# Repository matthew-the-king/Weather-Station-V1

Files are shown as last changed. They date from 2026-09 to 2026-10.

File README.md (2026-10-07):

# Weather-Station-V1
The Weather Station V1 is a Solar- and Battery-powered Weather Station that measures humidity, pressure, temperature, and air quality, and sends all data over Wi-Fi for a client to receive or records it to an SD card.
Weather_Station_2026-Oct-04_05-36-57PM-000_CustomizedView7621450915

## |FEATURES IN DEPTH|<br>
The Weather Station V1 uses multiple sensors to collect data; here is the list:<br>
1.STS40-AD1B-R3(Temperature Sensor)<br>
2.BMP581(Pressure Sensor)<br>
3.ENS160-BGLT(Air qaulity Sensor)<br>
4.SAM-M10Q-00B(GPS IC)<br>
To view the data the Weather Station V1 collects, the PCB has an SD card slot that records data over long periods and an ESP32-C3 that can send data over WiFi.<br>

<br>
The Weather Station V1 can be powered with a solar panel. To hook up the solar panel, connect the power wires with the correct polarity to the blue screw-in terminal. Here is the [link](https://www.amazon.com/ECO-WORTHY-Monocrystalline-Waterproof-Charging-Applications/dp/B01IFJ73X4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), it cost around $29(As of october 10, 2026), to the Solar panel I am using; any Solar panel that can supply over 2 amps and more than 20 volts will work.<br>
<br>
Weather_Station_2026-Oct-07_04-39-36AM-000_CustomizedView14020761017<br>
The Weather Station V1 features an LTC4162, which is a LiFePO4 battery step-down charger with a Power path. To set up the cell count properly, JP1 and JP4 must be bridged. 
The PCB includes a port for soldering a thermistor for battery protection.

The current configuration of the PCB requires 4 LiFePO4 batteries(https://www.digikey.com/en/products/detail/zeus-battery-products/PCIFR18650-1500/9828824)
The PCB has THT 18650 Battery holder footprint on the bottom side of the board, allowing for quick and easy connection of batteries to the PCB.<br>
<br>
The board has a USB-C port for each MCU to make programming as easy as possible, but in case the user does not want to use USB programming, there are also header pins on the other side of the
board that allow for ESP32 UART programming and STM32 serial wire debug and programming.<br>


<br>
## |PRODUCTION|<br>
To produce the PCB, use your preferred PCB manufacturer (PCBway, JLCPCB, etc.).  The Bill of Materials is listed here:<br>
* If Digi-Key does not have the part stocked, check other vendors like Mouser. <br>
*Prices as of October 10, 2026<br>

| Designator | Footprint | Qty | Value / Part | Part Link |Price|
|---|---|---:|---|---|---|
| BT5 | BAT_BK-18650-PC8 | 1 | BK-18650-PC8 | [Link](https://www.digikey.com/en/products/detail/mpd-memory-protection-devices/BK-18650-PC8/2330515)|$6.22|
| C1 | 0603 | 1 | 330nF | [Link](https://www.digikey.com/en/products/detail/tdk/CGA3E3X7R1H334K080AB/4931465)|$0.26|
| C10, C27, C3, C38, C39, C4, C40, C41, C45, C46, C5, C50, C51, C52, C53, C54, C6, C62, C63, C64, C9 | 0402 | 21 | 0.1uF |[Link](https://www.digikey.com/en/products/detail/samsung-electro-mechanics/CL05A104KA5NNNC/3886701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) | $0.38|
| C11, C37, C44, C57, C65 | 0402 | 5 | 10uF |[Link](https://www.digikey.com/en/products/detail/murata-electronics/GRM155R60J106ME15D/5877401) |$0.85|
| C12, C13, C16, C42, C43, C61, C66 | 0402 | 7 | 1uF |[Link](https://www.digikey.com/en/products/detail/samsung-electro-mechanics/CL05A105KO5NNNC/3886725) |$0.70|
| C14 | 0402 | 1 | 22nF |[Link](https://www.digikey.com/en/products/detail/murata-electronics/GRM155R71H223KA12D/965898) |$0.11|
| C15, C18, C2, C24, C26, C7 | 1210 | 6 | 10uF |[Link](https://www.digikey.com/en/products/detail/murata-electronics/GCJ32EC71H106KA01K/9867929) |$7.08|
| C17, C22, C23, C29, C60, C67, C68, C69 | 0603 | 8 | 0.1uF |[Link](https://www.digikey.com/en/products/detail/kemet/C0603C104K5RACTU/1465594)|$1.12|
| C25, C28 | CAP_EEH-ZA1V151P_PAN | 2 | 150uF |[Link](https://www.digikey.com/en/products/detail/panasonic-industry/EEH-ZA1V151P/3088122) |$3.52|
| C34, C35, C36 | 0805 | 3 | 220nF |[Link](https://www.digikey.com/en/products/detail/kemet/C0805C224K5RACTU/754753) |$0.93|
| C47, C48 | 0201 | 2 | C |Will Post link when Done with testing||
| C49 | 0603 | 1 | 4.7uF |[Link](https://www.digikey.com/en/products/detail/murata-electronics/GRM188R61E475KE11D/3900465) |$0.24|
| C55, C8 | 0603 | 2 | 22uF |[Link](https://www.digikey.com/en/products/detail/holy-stone-enterprise-co-ltd/C0603B226M010T/16895513) |$0.68|
| C56 | WCAP-PSHP_8X8.7_DXL_ | 1 | 470uF |[Link](https://www.digikey.com/en/products/detail/w%C3%BCrth-elektronik/875115252003/5147615) |$1.32|
| C58 | 0402 | 1 | 470pF |[Link](https://www.digikey.com/en/products/detail/murata-electronics/GRM1555C1H471JA01D/587210) |$0.10|
| C59 | 0402 | 1 | 100pF |[Link](https://www.digikey.com/en/products/detail/murata-electronics/GRM1555C1H101JA01D/3693829) |$0.11|
| D1, D5, D6 | D_SOD-123F | 3 | 40V |[Link](https://www.digikey.com/en/products/detail/smc-diode-solutions/DSS14U/8341859) |$0.63|
| D2 | D_SMA | 1 | D |[Link](https://www.digikey.com/en/products/detail/mcc-micro-commercial-components/SK310A-LTP/2642015) |$0.52|
| D3 | D_SOD-123 | 1 | Zener 16V |[Link](https://www.digikey.com/en/products/detail/diodes-incorporated/DDZ9703-7/5218356) |$0.36|
| D4 | D_SMA | 1 | 100V |[Link](https://www.digikey.com/en/products/detail/mcc-micro-commercial-components/SK310A-LTP/2642015) |$0.52|
| ESP32_USB1, STM32_USB1 | SAMESKY_UJ20-C-H-G-SMT-P16-TR | 2 | UJ20-C-H-G-SMT-1-P16-TR |[Link](https://www.digikey.com/en/products/detail/same-sky-formerly-cui-devices/UJ20-C-H-G-SMT-P16-TR/24818595) |$1.30|
| FB1, FB2 | 0603 | 2 | 120R |[Link](https://www.digikey.com/en/products/detail/pulse-electronics/PE-0603PFB121ST/5050544) |$0.20|
| J1 | GCT_MEM2075-00-140-01-A | 1 | MEM2075-00-140-01-A |[Link](https://www.digikey.com/en/products/detail/gct/MEM2075-00-140-01-A/9859614) |$1.92|
| J2 | TE_CONREVSMA002 | 1 | CONREVSMA002 |[Link](https://www.digikey.com/en/products/detail/te-connectivity-linx/CONREVSMA002/340145) |$2.78|
| J3 | PinHeader_1x05_P2.54mm_Vertical | 1 | Conn_01x05_Pin |2.54mm Male Header Pins|
| J4 | PinHeader_1x04_P2.54mm_Vertical | 1 | Conn_01x04_Pin |2.54mm Male Header Pins|
| J5 | OST_OSTTC020162 | 1 | Solar Panel |[Link](https://www.digikey.com/en/products/detail/on-shore-technology-inc/OSTTC020162/614549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) | $0.62|
| JP8, JP9 | PinSocket_1x02_P2.54mm_Vertical | 2 | Jumper_2_Open |2.54mm Male Header Pins|
| L1 | IND_PA4342.402NLT | 1 | 4uH |[Link](https://www.digikey.com/en/products/detail/pulse-electronics/PA4342-402NLT/5641799) |$1.16|
| L2 | 0201 | 1 | L |Will Post link when Done with testing||
| L3 | 1008 | 1 | 1.5uH |[Link](https://www.digikey.com/en/products/detail/murata-electronics/DFE252012P-1R5M-P2/5247259) |$0.22|
| Q10, Q9 | NPNBEC_SOT-23_OSI | 2 | BSR14 |[Link](https://www.digikey.com/en/products/detail/onsemi/BSR14/965251) |$0.96|
| Q11, Q14 | WDFN8_511DR_OSI-L | 2 | FDMC8327L |[Link](https://www.digikey.com/en/products/detail/onsemi/FDMC8327L/4314821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) |$3.00|
| Q3, Q4, Q5, Q6 | TDSON-8-1 | 4 | CSD18534Q5A |[Link](https://www.digikey.com/en/products/detail/texas-instruments/CSD18534Q5A/3830016) |$6.84|
| R1 | 1206 | 1 | 16mΩ |[Link](https://www.digikey.com/en/products/detail/littelfuse-inc/L4CL1206LR016DNR/18795436) |$1.31|
| R10, R11 | 2512 | 2 | 10MΩ |[Link](https://www.digikey.com/en/products/detail/bourns-inc/CHV2512-JW-106ELF/5175992) |$1.02|
| R12, R13, R8, R9 | 0603 | 4 | 330Ω |[Link](https://www.digikey.com/en/products/detail/yageo/RC0603FR-07330RL/727162) |$0.40|
| R14 | 0603 | 1 | 63.4k |[Link](https://www.digikey.com/en/products/detail/yageo/RT0603BRD0763K4L/1072610) |$0.10|
| R15, R16 | 0402 | 2 | 10k |[Link](https://www.digikey.com/en/products/detail/yageo/RC0402JR-0710KL/726418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) |$0.11|
| R2, R3, R39, R40 | 0402 | 4 | 4.7kΩ |[Link](https://www.digikey.com/en/products/detail/yageo/RC0402JR-074K7L/726477) |$0.44|
| R20, R25 | 0603 | 2 | 300Ω |[Link](https://www.digikey.com/en/products/detail/yageo/RC0603FR-07300RL/724356) |$0.20|
| R21, R22 | 2512 | 2 | 80.6Ω |[Link](https://www.digikey.com/en/products/detail/koa-speer-electronics-inc/RK73H3ATTE80R6F/10423948) |$0.62|
| R23, R24, R26, R47, R48, R51, R52, R7 | 2010 | 8 | 100Ω |[Link](https://www.digikey.com/en/products/detail/yageo/RT2010FKE07100RL/5945596) |$1.28|
| R27, R28, R29, R30 | 0402 | 4 | 5.1kΩ |[Link](https://www.digikey.com/en/products/detail/yageo/RC0402FR-075K1L/726624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) |$0.40|
| R31, R32, R33, R34, R37, R38, R43, R45, R49 | 0402 | 9 | 10kΩ |[Link](https://www.digikey.com/en/products/detail/yageo/RC0402JR-0710KL/726418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) |$0.99|
| R35, R36 | 0402 | 2 | 22Ω |[Link](https://www.digikey.com/en/products/detail/yageo/RC0402FR-0722RL/726562) |$0.22|
| R41 | 0402 | 1 | 100k |[Link](https://www.digikey.com/en/products/detail/yageo/RC0402FR-07100KL/726526) |$0.10|
| R42 | 0402 | 1 | 31.6kΩ |[Link](https://www.digikey.com/en/products/detail/panasonic-industry/ERA-2AEB3162X/2026187) |$0.11|
| R44, R53 | 0402 | 2 | 100kΩ |[Link](https://www.digikey.com/en/products/detail/yageo/RC0402FR-07100KL/726526) |$0.10|
| R46 | MSRSF3920P1L00D2P0 | 1 | 1mΩ |[Link](https://www.digikey.com/en/products/detail/susumu/MSRSF3920P-1L00-D2P0/24396792) |$1.74|
| R50 | 0805 | 1 | 32mΩ |[Link](https://www.digikey.com/en/products/detail/vishay-dale/WSLP0805R0320FEA/9755276) |$1.29|
| S1 | SW_SKRPABE010 | 1 | SKRPABE010 |[Link](https://www.digikey.com/en/products/detail/alps-alpine/SKRPABE010/18768948) |$0.22|
| TH1 | PinHeader_1x02_P1.00mm_Vertical | 1 | 103AT2 |[Link](https://www.digikey.com/en/products/detail/semitec-usa-corp/103AT-2/16579059?s=N4IgTCBcDaIIwAYDMBBAKhAugXyA) |$0.68|
| U1 | UFQFPN-32_STM | 1 | STM32U385KGU6 |[Link](https://www.digikey.com/en/products/detail/stmicroelectronics/STM32U385KGU6/26092104) |$7.31|
| U10 | VQFN20_RGR_TEX | 1 | BQ76907RGRR |[Link](https://www.digikey.com/en/products/detail/texas-instruments/BQ76907RGRR/22077514) |$2.01|
| U11 | SOT-23-5 | 1 | MIC5504-1.8YM5 |[Link](https://www.digikey.com/en/products/detail/microchip-technology/MIC5504-1-8YM5-TR/5209404) |$0.16|
| U12, U13 | PSON50P145X100X60-6N | 2 | TPD4S012DRYR |[Link](https://www.digikey.com/en/products/detail/texas-instruments/TPD4S012DRYR/2037539) |$2.38|
| U14 | IC_MCP16362T-E_NMX | 1 | MCP16362T-E_NMX |[Link](https://www.digikey.com/en/products/detail/microchip-technology/MCP16362T-E-NMXVAO/14291783) |$2.33|
| U2 | QFN10_BMP581_BOS | 1 | BMP581 |[Link](https://www.digikey.com/en/products/detail/bosch-sensortec/BMP581/16036134) |$3.35|
| U3 | STS4X | 1 | STS4X |[Link](https://www.digikey.com/en/products/detail/sensirion-ag/STS40-AD1B-R3/16020549) |$0.72|
| U4 | XDCR_ENS210-LQFM | 1 | ENS210-LQFM |[Link](https://www.digikey.com/en/products/detail/sciosense/ENS210-LQFM/6490747) |$1.62|
| U5 | XDCR_ENS160-BGLT | 1 | ENS160-BGLT |[Link](https://www.digikey.com/en/products/detail/sciosense/ENS160-BGLT/16129831) |$5.72|
| U6 | QFN50P500X500X90-33N | 1 | LTC4162IUFD-FAD_PBF |[Link](https://www.digikey.com/en/products/detail/analog-devices-inc/LTC4162IUFD-FAD-PBF/9446112) |$9.96|
| U7 | XCVR_SAM-M10Q-00B | 1 | SAM-M10Q-00B |[Link](https://www.digikey.com/en/products/detail/u-blox/SAM-M10Q-00B/16672678) |$13.75|
| U8 | QFN50P500X500X90-33N | 1 | ESP32-C3FH4 |[Link](https://www.digikey.com/en/products/detail/espressif-systems/ESP32-C3FH4/14115592) |$2.50|
| Y3 | OSC_ECS-2520S33-400-FN-TR | 1 | 40MHZ |[Link](https://www.digikey.com/en/products/detail/ecs-inc/ECS-2520S33-400-FN-TR/6578428) |$2.25|

Make sure you also purchase an antenna for the RF port; any SMA-Male antenna works. Here is a [link](https://www.digikey.com/en/products/detail/inventek-systems/W24-ASMA-M/4959494) for one.<br>
The total cost of all the PCB components is 135.59 dollars as of right now, with shipping being around an extra $5; when I add the PI filter stuff, it will only go up a dollar max.<br>
I would greatly recommend using a PCB stencil to make soldering components easier, as some of the components are quite small. Remember, in order for the battery functionality to work, JP1 and JP4 must be bridged.<br>
<br>

## |Weather Station Case|<br>
I CAD'd a 3D-printable case for the Weather Station V1 PCB; it has two parts: a front plate and a container part.
There are M.2 threaded insert holes on the container part, so you must purchase threaded inserts and M.2 screws.<br>
<br>

## |Firmware|<br>
So far, I have only added main.cpp, which should be placed in an STM32CubeIDE project.  No code has been written into it yet because I do not have the board to program yet. 

## |Purpose Of Project |<br>
The purpose of the Weather Station V1 was to enhance my understanding of RF applications and battery- and solar-powered devices. Throughout making this project, I understood RF design better and overall PCB design.
I hope this knowledge will allow me to make better, more reliable, and cooler projects in the future.

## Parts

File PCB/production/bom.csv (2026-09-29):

Designator | Footprint | Quantity | Value | LCSC Part #
BT5 | BAT_BK-18650-PC8 | 1 | BK-18650-PC8
C1 | 0603 | 1 | 330nF
C10, C27, C3, C38, C39, C4, C40, C41, C45, C46, C5, C50, C51, C52, C53, C54, C6, C62, C63, C64, C9 | 0402 | 21 | 0.1uF
C11, C37, C44, C57, C65 | 0402 | 5 | 10uF
C12, C13, C16, C42, C43, C61, C66 | 0402 | 7 | 1uF
C14 | 0402 | 1 | 22nF
C15, C18, C2, C24, C26, C7 | 1210 | 6 | 10uF
C17, C22, C23, C29, C60, C67, C68, C69 | 0603 | 8 | 0.1uF
C25, C28 | CAP_EEH-ZA1V151P_PAN | 2 | 150uF
C34, C35, C36 | 0805 | 3 | 220nF
C47, C48 | 0201 | 2 | C
C49 | 0603 | 1 | 4.7uF
C55, C8 | 0603 | 2 | 22uF
C56 | WCAP-PSHP_8X8.7_DXL_ | 1 | 470uF
C58 | 0402 | 1 | 470pF
C59 | 0402 | 1 | 100pF
D1, D5, D6 | D_SOD-123F | 3 | 40V
D2 | D_SMA | 1 | D
D3 | D_SOD-123 | 1 | Zener 16V
D4 | D_SMA | 1 | 100V
ESP32_USB1, STM32_USB1 | SAMESKY_UJ20-C-H-G-SMT-P16-TR | 2 | UJ20-C-H-G-SMT-1-P16-TR
FB1, FB2 | 0603 | 2 | 120R
J1 | GCT_MEM2075-00-140-01-A | 1 | MEM2075-00-140-01-A
J2 | TE_CONREVSMA002 | 1 | CONREVSMA002
J3 | PinHeader_1x05_P2.54mm_Vertical | 1 | Conn_01x05_Pin
J4 | PinHeader_1x04_P2.54mm_Vertical | 1 | Conn_01x04_Pin
J5 | OST_OSTTC020162 | 1 | Solar Panel
JP1, JP2, JP3, JP4, JP5, JP6, JP7 | SolderJumper-2_P1.3mm_Open_TrianglePad1.0x1.5mm | 7 | Jumper_2_Open
JP8, JP9 | PinSocket_1x02_P2.54mm_Vertical | 2 | Jumper_2_Open
L1 | IND_PA4342.402NLT | 1 | 4uH
L2 | 0201 | 1 | L
L3 | 1008 | 1 | 1.5uH
Q10, Q9 | NPNBEC_SOT-23_OSI | 2 | BSR14
Q11, Q14 | WDFN8_511DR_OSI-L | 2 | FDMC8327L
Q3, Q4, Q5, Q6 | TDSON-8-1 | 4 | CSD18534Q5A
R1 | 1206 | 1 | 16mΩ
R10, R11 | 2512 | 2 | 10MΩ
R12, R13, R8, R9 | 0603 | 4 | 330Ω
R14 | 0603 | 1 | 63.4k
R15, R16 | 0402 | 2 | 10k
R2, R3, R39, R40 | 0402 | 4 | 4.7kΩ
R20, R25 | 0603 | 2 | 300Ω
R21, R22 | 2512 | 2 | 80.6Ω
R23, R24, R26, R47, R48, R51, R52, R7 | 2010 | 8 | 100Ω
R27, R28, R29, R30 | 0402 | 4 | 5.1kΩ
R31, R32, R33, R34, R37, R38, R43, R45, R49 | 0402 | 9 | 10kΩ
R35, R36 | 0402 | 2 | 22Ω
R41 | 0402 | 1 | 100k
R42 | 0402 | 1 | 31.6kΩ
R44, R53 | 0402 | 2 | 100kΩ
R46 | MSRSF3920P1L00D2P0 | 1 | 1mΩ
R50 | 0805 | 1 | 32mΩ
S1 | SW_SKRPABE010 | 1 | SKRPABE010
TH1 | PinHeader_1x02_P1.00mm_Vertical | 1 | 103AT2
U1 | UFQFPN-32_STM | 1 | STM32U385KGU6
U10 | VQFN20_RGR_TEX | 1 | BQ76907RGRR
U11 | SOT-23-5 | 1 | MIC5504-1.8YM5
U12, U13 | PSON50P145X100X60-6N | 2 | TPD4S012DRYR
U14 | IC_MCP16362T-E_NMX | 1 | MCP16362T-E_NMX
U2 | QFN10_BMP581_BOS | 1 | BMP581
U3 | STS4X | 1 | STS4X
U4 | XDCR_ENS210-LQFM | 1 | ENS210-LQFM
U5 | XDCR_ENS160-BGLT | 1 | ENS160-BGLT
U6 | QFN50P500X400X80-29N | 1 | LTC4162IUFD-FAD_PBF
U7 | XCVR_SAM-M10Q-00B | 1 | SAM-M10Q-00B
U8 | QFN50P500X500X90-33N | 1 | ESP32-C3FH4
Y3 | OSC_ECS-2520S33-400-FN-TR | 1 | 40MHZ

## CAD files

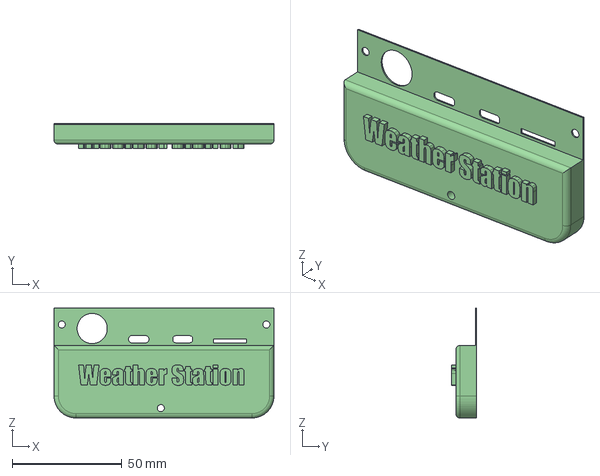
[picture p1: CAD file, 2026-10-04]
CAD/Front_Plate.step
100.0 x 11.5 x 50.0 mm

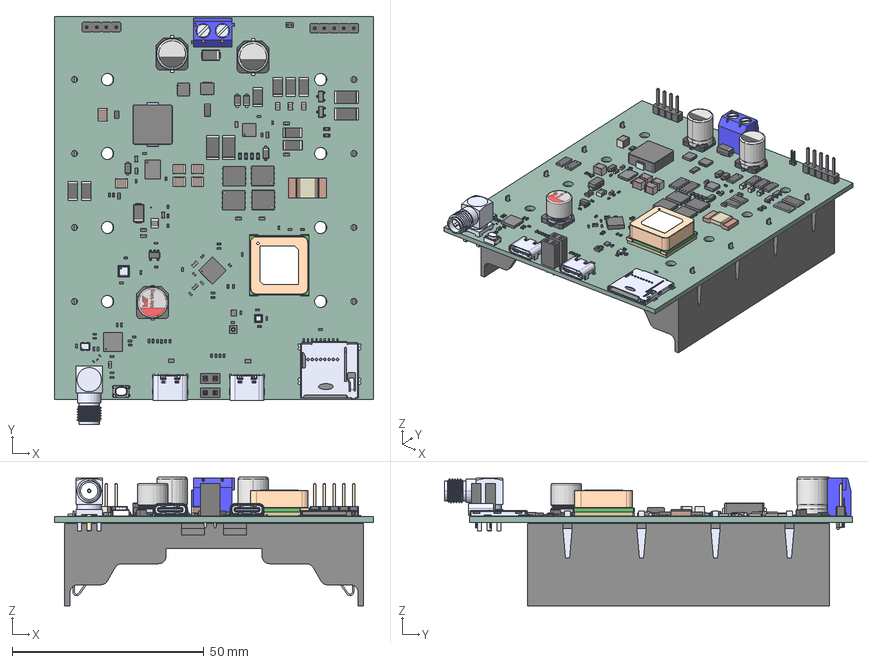
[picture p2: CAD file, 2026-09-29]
PCB/Weather_Station.step
83.4 x 106.5 x 33.6 mm
C_0603_1608Metric x 12
C_0402_1005Metric x 38
R_0402_1005Metric x 23
MSRSF3920P-1L00-D2P0
ECS-2520S33-200-FN-TR
C_0201_0603Metric x 2
R_0603_1608Metric x 7
R_0805_2012Metric
PinSocket_1x02_P2.54mm_Vertical x 2
EEHZF1E151P x 2
C_1210_3225Metric x 6
SKRPABE010
C_0805_2012Metric x 3
Same_Sky_UJ20-C-H-G-SMT-P16-TR x 2
SOT23 x 2
RGR20
R_2512_6332Metric x 4
R_2010_5025Metric x 8
MEM2075-00-140-01-A
L_1008_2520Metric
148907-01_Publikationsmodell STS4x
L_0603_1608Metric x 2
LTC2323HUFD-14#PBF
ENS210-LQFM
BMP581
SAM-M10Q-00B
TDSON_8_1 x 4
CONREVSMA002
D_SOD_123F x 3
ESP32-C3FH4
D_SOD-123
Base_Φ8Capacitor
capicitor_8x8.7x3.1
DRY6 x 2
L_0201_0603Metric
PinHeader_1x04_P254mm_Vertical
R_1206_3216Metric
PA4342.402NLT
SOT-23-5
D_SMA x 2
PinHeader_1x02_P100mm_Vertical
PinHeader_1x05_P254mm_Vertical
ENS160-BGLM
OSTTC020162
BK-18650-PC8
Wea2D00_PCB

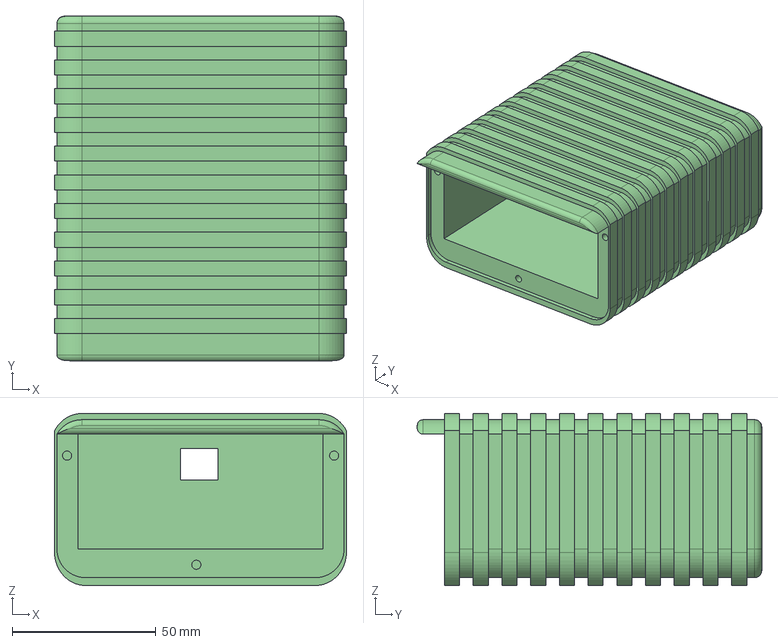
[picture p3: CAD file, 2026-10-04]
CAD/Container.step
101.7 x 120.0 x 60.0 mm

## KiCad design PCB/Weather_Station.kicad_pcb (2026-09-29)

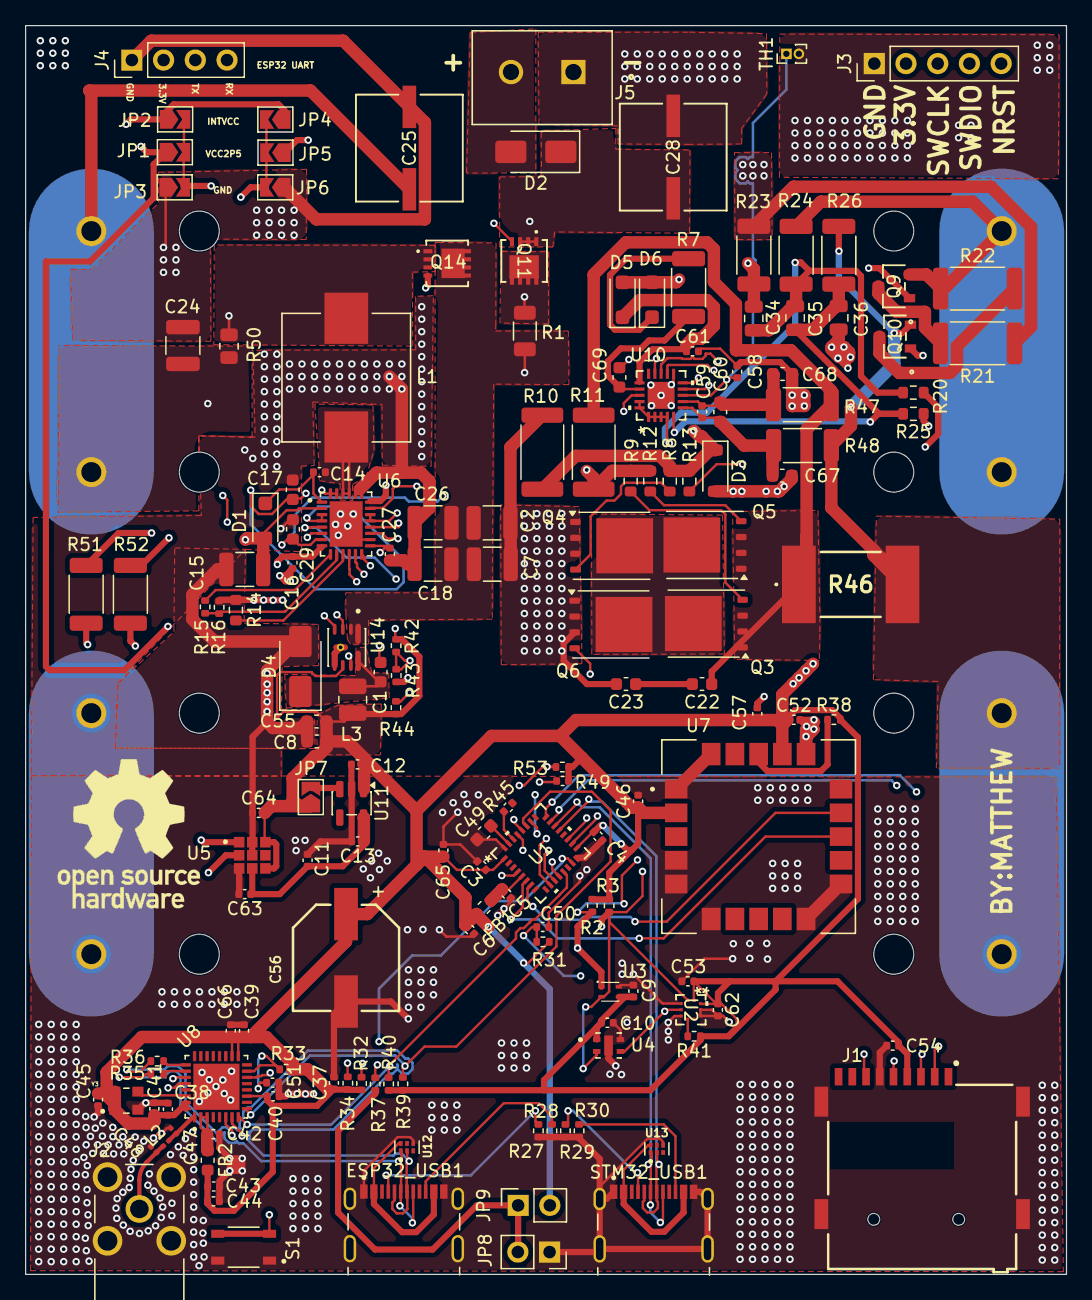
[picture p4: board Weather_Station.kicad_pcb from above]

Board: 4 copper layers, 83.4 x 100.0 mm, 161 parts (1 on the bottom side), 94 nets.

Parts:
BT5: BK-18650-PC8; BAT_BK-18650-PC8
C1: 330nF; C_0603_1608Metric
C2, C7, C15, C18, C24, C26: 10uF; C_1210_3225Metric
C3, C4, C5, C6, C9, C10, C27, C38, C39, C40, C41, C45, C46, C50, C51, C52, C53, C54, C62, C63, C64: 0.1uF; C_0402_1005Metric
C8, C55: 22uF; C_0603_1608Metric
C11, C37, C44, C57, C65: 10uF; C_0402_1005Metric
C12, C13, C16, C42, C43, C61, C66: 1uF; C_0402_1005Metric
C14: 22nF; C_0402_1005Metric
C17, C22, C23, C29, C60, C67, C68, C69: 0.1uF; C_0603_1608Metric
C25, C28: 150uF; CAP_EEH-ZA1V151P_PAN
C34, C35, C36: 220nF; C_0805_2012Metric
C47, C48: C; C_0201_0603Metric
C49: 4.7uF; C_0603_1608Metric
C56: 470uF; WCAP-PSHP_8X8.7_DXL_
C58: 470pF; C_0402_1005Metric
C59: 100pF; C_0402_1005Metric
D1, D5, D6: 40V; D_SOD-123F
D2: D; D_SMA
D3: Zener 16V; D_SOD-123
D4: 100V; D_SMA
ESP32_USB1: UJ20-C-H-G-SMT-1-P16-TR; SAMESKY_UJ20-C-H-G-SMT-P16-TR
FB1, FB2: 120R; L_0603_1608Metric
J1: MEM2075-00-140-01-A; GCT_MEM2075-00-140-01-A
J2: CONREVSMA002; TE_CONREVSMA002
J3: Conn_01x05_Pin; PinHeader_1x05_P2.54mm_Vertical
J4: Conn_01x04_Pin; PinHeader_1x04_P2.54mm_Vertical
J5: Solar Panel; OST_OSTTC020162
JP1, JP2, JP3, JP4, JP5, JP6, JP7: Jumper_2_Open; SolderJumper-2_P1.3mm_Open_TrianglePad1.0x1.5mm
JP8, JP9: Jumper_2_Open; PinSocket_1x02_P2.54mm_Vertical
L1: 4uH; IND_PA4342.402NLT
L2: L; L_0201_0603Metric
L3: 1.5uH; L_1008_2520Metric
Q3, Q4, Q5, Q6: CSD18534Q5A; TDSON-8-1
Q9, Q10: BSR14; NPNBEC_SOT-23_OSI
Q11, Q14: FDMC8327L; WDFN8_511DR_OSI-L
R1: 16mΩ; R_1206_3216Metric
R2, R3, R39, R40: 4.7kΩ; R_0402_1005Metric
R7, R23, R24, R26, R47, R48, R51, R52: 100Ω; R_2010_5025Metric
R8, R9, R12, R13: 330Ω; R_0603_1608Metric
R10, R11: 10MΩ; R_2512_6332Metric
R14: 63.4k; R_0603_1608Metric
R15, R16: 10k; R_0402_1005Metric
R20, R25: 300Ω; R_0603_1608Metric
R21, R22: 80.6Ω; R_2512_6332Metric
R27, R28, R29, R30: 5.1kΩ; R_0402_1005Metric
R31, R32, R33, R34, R37, R38, R43: 10kΩ; R_0402_1005Metric
R35, R36: 22Ω; R_0402_1005Metric
R41: 100k; R_0402_1005Metric
R42: 31.6kΩ; R_0402_1005Metric
R44, R53: 100kΩ; R_0402_1005Metric
R45, R49: 10kΩ; C_0402_1005Metric
R46: 1mΩ; MSRSF3920P1L00D2P0
R50: 32mΩ; R_0805_2012Metric
S1: SKRPABE010; SW_SKRPABE010
STM32_USB1: UJ20-C-H-G-SMT-1-P16-TR; SAMESKY_UJ20-C-H-G-SMT-P16-TR
TH1: 103AT2; PinHeader_1x02_P1.00mm_Vertical
U1: STM32U385KGU6; UFQFPN-32_STM
U2: BMP581; QFN10_BMP581_BOS
U3: STS4X
U4: ENS210-LQFM; XDCR_ENS210-LQFM
U5: ENS160-BGLT; XDCR_ENS160-BGLT
U6: LTC4162IUFD-FAD_PBF; QFN50P500X400X80-29N
U7: SAM-M10Q-00B; XCVR_SAM-M10Q-00B
U8: ESP32-C3FH4; QFN50P500X500X90-33N
U10: BQ76907RGRR; VQFN20_RGR_TEX
U11: MIC5504-1.8YM5; SOT-23-5
U12, U13: TPD4S012DRYR; PSON50P145X100X60-6N
U14: MCP16362T-E_NMX; IC_MCP16362T-E_NMX
Y3: 40MHZ; OSC_ECS-2520S33-400-FN-TR

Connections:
+1V8: C11.1, C13.1, C63.1, U5.4 (VDD), U11.5 (VOUT)
+3.3V: C3.1, C4.1, C6.1, C8.1, C9.1, C10.1, C12.1, C27.1, C37.1, C38.1, C39.1, C40.1, C41.1, C43.1, C44.1, C45.1, C46.1, C52.1, C53.1, C54.1, C55.1, C56.1, C57.1, C62.1, C64.1, C65.1, C66.1, FB1.2, FB2.2, J1.P4 (VDD), J3.2, J4.2, JP7.1 (A), JP9.2 (B), L3.2, R2.1, R3.2, R31.1, R32.1, R33.2, R34.2, R38.2, R39.1, R40.1, R41.1, R42.1, R44.1, R49.1, R53.1, U1.1 (VDD), U1.17 (VDD), U2.1 (VDDIO), U2.10 (VDD), U3.3 (VDD), U4.1 (VDD), U5.5 (VDDIO), U5.7 (~CS), U6.15 (DVCC), U7.2 (V_IO), U7.17 (VCC), U8.11 (VDD3P3_RTC), U8.17 (VDD3P3_CPU), U8.18 (VDD_SPI), U8.31 (VDDA), U8.32 (VDDA__1), U11.1 (VIN), U14.6 (BD), Y3.1 (TRI_STATE), Y3.4 (VDD)
+BATT: BT5.3+, BT5.4+, C24.1, C25.1, D5.2 (A), D6.2 (A), R21.1, R23.1, R50.2, U6.19 (BATSENS+), U6.20 (CSN)
-BATT: C2.2, C3.2, C4.2, C5.2, C6.2, C7.2, C8.2, C9.2, C10.2, C11.2, C12.2, C13.2, C15.2, C16.2, C17.2, C18.2, C23.2, C24.2, C25.2, C26.2, C27.2, C28.2, C29.2, C36.2, C37.2, C38.2, C39.2, C40.2, C41.2, C42.2, C43.2, C44.2, C45.2, C46.2, C47.2, C48.2, C49.2, C50.2, C51.2, C52.2, C53.2, C54.2, C55.2, C56.2, C57.2, C58.2, C61.1, C62.2, C63.2, C64.2, C65.2, C66.2, C67.2, C68.1, C69.1, D3.2 (A), D4.2 (A), ESP32_USB1.A1_B12 (GND), ESP32_USB1.A12_B1, ESP32_USB1.SH1 (SHIELD), ESP32_USB1.SH2 (SHIELD__1), ESP32_USB1.SH3 (SHIELD__2), ESP32_USB1.SH4 (SHIELD__3), J1.P6 (VSS), J1.SH1 (SHIELD), J1.SH2 (SHIELD__1), J1.SH3 (SHIELD__2), J1.SH4 (SHIELD__3), J2.2, J2.3, J2.4, J2.5, J3.1, J4.1, J5.1, JP3.1 (A), JP6.1 (A), JP8.1 (A), Q4.1 (S), Q4.2 (S), Q4.3 (S), Q6.1 (S), Q6.2 (S), Q6.3 (S), R10.2, R14.2, R16.2, R27.2, R28.2, R29.2, R30.2, R43.2, S1.1, S1.2, STM32_USB1.A1_B12 (GND), STM32_USB1.A12_B1, STM32_USB1.SH1 (SHIELD), STM32_USB1.SH2 (SHIELD__1), STM32_USB1.SH3 (SHIELD__2), STM32_USB1.SH4 (SHIELD__3), TH1.2, U1.16 (VSS), U1.32 (VSS), U2.3 (VSS), U2.5 (SDO), U2.8 (VSS), U2.9 (VSS), U3.4 (VSS), U4.4 (VSS), U4.5 (VSS__1), U5.3 (MISO/ADDR), U5.8 (VSS), U5.9 (VSS__1), U6.16 (SYNC), U6.23 (PGND), U6.24 (PGND__1), U6.29 (AGND), U7.1 (GND), U7.4 (GND__1), U7.5 (GND__2), U7.6 (GND__3), U7.10 (GND__4), U7.11 (GND__5), U7.15 (GND__6), U7.16 (GND__7), U7.20 (GND__8), U8.33 (GND), U10.11 (VSS), U10.21 (EPAD), U11.2 (GND), U12.4 (GND), U13.4 (GND), U14.5 (GND), U14.9 (EP), U14.10, Y3.2 (GND)
/ALERT: R49.2, U1.19 (PA9), U10.14 (ALERT)
/BATFET: Q14.4 (G), U6.22 (BATFET)
/BOOST: C1.1, U14.7 (BOOST)
/BT1+: BT5.1+, BT5.2+, BT5.3-, BT5.4-, Q9.2, R22.1, R24.1
/BT1-: BT5.1-, BT5.2-, Q10.2, R26.1, R46.2, R48.1
/CELLS0: R52.2, U6.17 (CELLS0)
/CELLS1: R51.2, U6.18 (CELLS1)
/CHG: D3.1 (K), R8.1, R10.1, R13.1, U10.10 (CHG)
/CHIP_EN: R37.2, U1.15 (PB1), U8.7 (CHIP_EN)
/CLN: C2.1, C7.1, C17.1, C18.1, C26.1, Q14.5 (D), Q14.6, Q14.7, Q14.8, Q14.9, R1.2, U6.3 (VOUTA), U6.4 (CLN), U6.27 (VOUT), U6.28 (VOUT__1), U14.1 (VIN), U14.2 (EN)
/CLP: Q11.5 (D), R1.1, U6.5 (CLP)
/DSG: R9.2, R11.1, R12.2, U10.9 (DSG)
/ESP32_RX: J4.4, U8.27 (GPIO20/U0RXD)
/ESP32_TX: J4.3, U8.28 (GPIO21/U0TXD)
/ESP_SCL: R40.2, U1.13 (PA7), U8.8 (GPIO3)
/ESP_SDA: R39.2, U1.27 (PB4), U8.9 (GPIO4/MTMS)
/GPIO_9: C51.1, R33.1, S1.3, S1.4, U8.15 (GPIO9)
/GPS_RX: U1.7 (PA1), U7.14 (RXD)
/GPS_TX: U1.6 (PA0), U7.13 (TXD)
/INTVCC: C15.1, D1.2 (A), JP2.1 (A), JP4.1 (A), U6.2 (INTVCC)
/MISO: J1.P7 (DAT0), U1.12 (PA6)
/MOSI: J1.P3 (CMD), U1.28 (PB5)
/NRST: C50.1, J3.5, R31.2, U1.4 (NRST)
/PG: R44.2, U14.4 (PG)
/REGSRC: C61.2, D5.1 (K), U10.16 (REGSRC)
/SCL_1: R3.1, U1.29 (PB6), U2.2 (SCK), U3.2 (SCL), U4.2 (SCL), U5.2 (SCLK/SCL), U6.13 (SCL), U10.12 (SCL)
/SDA_1: R2.2, U1.26 (PB3), U2.4 (SDI), U3.1 (SDA), U4.3 (SDA), U5.1 (MOSI/SDA), U6.14 (SDA), U10.13 (SDA)
/SMBALERT: R53.2, U1.18 (PA8), U6.12 (~SMBALERT)
/SPI_CS: J1.P2 (CD/DAT3), U1.10 (PA4)
/SPI_SCK: J1.P5 (CLK), U1.11 (PA5)
/SRN: C59.1, C60.1, C68.2, R47.2, U10.7 (SRN)
/SRP: C59.2, C60.2, C67.1, R48.2, U10.6 (SRP)
/SWCLK: J3.3, U1.24 (PA14)
/SWDIO: J3.4, U1.23 (PA13)
/TS: C58.1, TH1.1, U10.8 (TS)
/USB_ESP32_DN: ESP32_USB1.A7 (DN1), ESP32_USB1.B7 (DN2), R36.2, U12.2 (D-)
/USB_ESP32_DP: ESP32_USB1.A6 (DP1), ESP32_USB1.B6 (DP2), R35.2, U12.1 (D+)
/USB_STM32_DN: STM32_USB1.A7 (DN1), STM32_USB1.B7 (DN2), U1.21 (PA11), U13.2 (D-)
/USB_STM32_DP: STM32_USB1.A6 (DP1), STM32_USB1.B6 (DP2), U1.22 (PA12), U13.1 (D+)
/VC0: C35.2, C36.1, R25.2, R26.2, U10.5 (VC0)
/VC1: C34.2, C35.1, R20.2, R24.2, U10.1 (VC4), U10.2 (VC3), U10.3 (VC2), U10.4 (VC1), U10.19 (VC6), U10.20 (VC5)
/VC7: C34.1, R23.2, U10.18 (VC7)
/VCC2P5: C16.1, JP1.1 (A), JP5.1 (A), U6.8 (VCC2P5)
/VDD3p3: C42.1, FB2.1, U8.2 (VDD3P3), U8.3 (VDD3P3__1)
unnamed: C22.1, Q3.1 (S), Q3.2 (S), Q3.3 (S), Q5.1 (S), Q5.2 (S), Q5.3 (S), R11.2, R46.1, R47.1
unnamed: C22.2, C23.1
unnamed: C48.1, J2.1, L2.1
unnamed: C14.1, D1.1 (K), U6.1 (BOOST)
unnamed: D2.2 (A), J5.2
unnamed: C28.1, C29.1, D2.1 (K), Q11.1 (S), Q11.2 (S), Q11.3 (S), U6.7 (VIN)
unnamed: C1.2, D4.1 (K), L3.1, U14.8 (SW)
unnamed: D6.1 (K), R7.1
unnamed: ESP32_USB1.A5 (CC1), R27.1
unnamed: ESP32_USB1.B5 (CC2), R28.1
unnamed: ESP32_USB1.A4_B9 (VBUS), ESP32_USB1.A9_B4, U12.6 (VBUS)
unnamed: JP1.2 (B), JP2.2 (B), JP3.2 (B), R52.1
unnamed: JP4.2 (B), JP5.2 (B), JP6.2 (B), R51.1
unnamed: JP7.2 (B), U11.3 (EN)
unnamed: JP8.2 (B), JP9.1 (A), R37.1
unnamed: Q3.5 (D), Q4.5 (D), Q5.5 (D), Q6.5 (D)
unnamed: Q3.4 (G), R9.1
unnamed: Q4.4 (G), R8.2
unnamed: Q5.4 (G), R12.1
unnamed: Q6.4 (G), R13.2
unnamed: Q9.1, R20.1
unnamed: Q9.3, R21.2
unnamed: Q10.1, R25.1
unnamed: Q10.3, R22.2
unnamed: Q11.4 (G), U6.6 (INFET)
unnamed: R29.1, STM32_USB1.A5 (CC1)
unnamed: R30.1, STM32_USB1.B5 (CC2)
unnamed: STM32_USB1.A4_B9 (VBUS), STM32_USB1.A9_B4, U13.6 (VBUS)
unnamed: R45.1, U1.30 (PB7-BOOT0)
unnamed: C49.1, U1.31 (VCAP)
unnamed: C5.1, FB1.1, U1.5 (VDDA)
unnamed: R41.2, U2.6 (CSB)
unnamed: L1.2, Q14.1 (S), Q14.2 (S), Q14.3 (S), R50.1, U6.21 (CSP)
unnamed: R15.2, R16.1, U6.10 (NTC)
unnamed: R15.1, U6.9 (NTCBIAS)
unnamed: R14.1, U6.11 (RT)
unnamed: C14.2, L1.1, U6.25 (SW), U6.26 (SW__1)
unnamed: R38.1, U7.18 (~RESET)
unnamed: R32.2, U8.6 (GPIO2)
unnamed: R34.1, U8.14 (GPIO8)
unnamed: R36.1, U8.25 (GPIO18/USB_D-)
unnamed: R35.1, U8.26 (GPIO19/USB_D+)
unnamed: C47.1, L2.2, U8.1 (LNA_IN)
unnamed: U8.30 (XTAL_P), Y3.3 (OUTPUT)
unnamed: C69.2, R7.2, U10.17 (BAT)
unnamed: R42.2, R43.1, U14.3 (FB)

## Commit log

2026-09-29 Enhance README with detailed Weather Station V1 features
    Updated the description for clarity and added detailed features of the Weather Station V1, including sensor information and power setup instructions.
2026-09-29 Update README with solar panel and production info
    Added additional details about powering the Weather Station V1 with solar panel and PCB production recommendations.
2026-09-29 Update README with PCB battery holder info
    Added details about the PCB battery holder and clarified battery bridging requirements.
2026-09-29 Update README with USB-C and programming details
    Added information about USB-C port and programming options for the board.
2026-09-30 Organized repo
    [Weather_Station.kicad_pcb, Weather_Station.step, bom.csv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]
2026-09-30 Update README with Bill of Materials and soldering tips
    Added a detailed Bill of Materials for PCB production and recommendations for soldering.
2026-09-30 Update README with soldering tips and project purpose
    Added recommendation for using a PCB stencil and clarified battery functionality requirements.
2026-09-30 Add part link for BT5 in README
    Added a link to the part for BT5 in the Bill of Materials.
2026-09-30 Update Bill of Materials with part links
2026-09-30 Update resistor links in README.md
2026-10-01 Update README with thermistor port information
    Added a port for thermistor soldering for battery protection.
2026-10-04 Cad added
    [Container.step, Front_Plate.step]
2026-10-04 Update README with antenna and case details
    Added information about antenna purchase and a 3D printable case for the Weather Station V1 PCB.
2026-10-04 Revise README for case description and firmware section
    Updated the README to improve clarity and added a section for firmware.
2026-10-06 Update BOM with pricing and additional notes
    Added price information for components and a note about total cost.
2026-10-06 Update Bill of Materials table format
    Removed the 'Price' column from the Bill of Materials table in the README.
2026-10-07 Revise Bill of Materials with pricing details
    Updated the Bill of Materials with prices and additional components.
2026-10-07 Update Bill of Materials with pricing and links
    Added pricing information and part links to the Bill of Materials.
2026-10-07 Revise component cost and shipping information
    Updated total cost of PCB components and shipping details.
